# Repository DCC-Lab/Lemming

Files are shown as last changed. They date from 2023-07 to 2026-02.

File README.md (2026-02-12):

# LEM: Lemming Enumeration Module
Authors: Authors: Gabriel Bergeron*, Mireille Quémener*, Thomas Shooner, Christopher Mathault, Nathan Bérubé, Daniel Côté, Dominique Fauteux, Pierre Legagneux

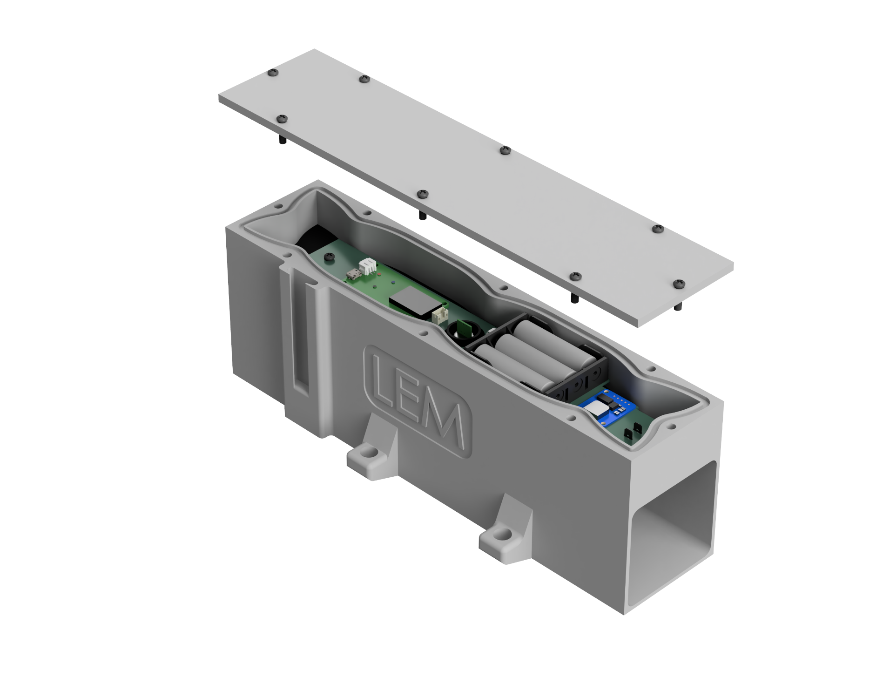
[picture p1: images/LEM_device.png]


## Context
This project focuses on the development of a monitoring device for small mammals, specifically targeting the lemming. The device is designed for deployment in extreme environments, such as the Arctic.

## How it works
The LEM functions as a **passive event logger** using an infrared sensor to detect the passage of small mammals, who emmit IR radiation.
- **Detection Trigger:** The device uses a Passive Infrared (PIR) sensor (AM312) positioned at the intersection of the tunnel and the electronics enclosure. When a small mammal enters the tube, its body heat creates a thermal contrast that triggers the sensor.
- **Wake-on-Interrupt:** To minimize battery consumption, the microcontroller remains in a "deep sleep" state. The PIR sensor is the only component that actively wakes the FireBeetle ESP32 by sending a high signal to a specific I/O pin when motion is detected.
- **Data Logging:** Once awakened, the system immediately pulls a precise date and time from the Real-Time Clock (RTC). This information is saved as a single timestamp entry in the onboard SPIFFS (Serial Peripheral Interface Flash File System) memory. The RTC ensures long-term accurate time keeping even in cold weather. 
- **No Species Identification:** It is important to note that the sensor is **species-blind**; it records the presence of an animal based on heat and motion but cannot distinguish between different small mammals, such as brown lemmings, collared lemmings, or shrews.

### Mechanical Assembly
The LEM device is designed as single-unit instrument to withstand extreme Arctic conditions, including flooding, permafrost, and sub-zero temperatures.
- **Main body:** of a $2.5 \times 2.5$ inch rectangular tunnel integrated with a top-mounted electronics enclosure. The unit is manufactured via thermoplastic molding using black MD-70 polyurethane elastomer, chosen for its durability and resistance to UV degradation and extreme temperatures.
- **Waterproofing:** The electronics lid is secured with screws and sealed against a rubber gasket. The PIR sensor and the power switch are further sealed into the chassis using epoxy resin to prevent water infiltration.
- **Deployment:** The device is placed directly on the ground and secured along small mammal paths using metal pegs. Its tunnel dimensions are specifically designed to be compatible with existing live-traps to ensure consistent animal usage probabilities.

### Electronic System
The LEM circuit is optimized for ultra-low power consumption, enabling autonomous operation in remote environments for over a year on standard AA alkaline batteries.
- **Microcontroller:** we selected the **DFRobot FireBeetle ESP32-E** for its deep-sleep capabilities and 1mW standby power draw (for the circuit in this project).
- **Sensing:** Uses an **AM312 Passive Infrared (PIR) sensor**. When motion is detected in the tunnel, the PIR signal wakes the microcontroller to log the event.
- **Data Logging:** Each detection is recorded as a time-stamped entry in the FireBeetle’s onboard **SPIFFS memory**.
- **Timekeeping:** Includes an **Adafruit PCF8523 Real-Time Clock (RTC)** module powered by a dedicated lithium coin cell to maintain accurate time across deep-sleep cycles and cold-induced power fluctuations.
- **Power Supply:** Operates on **three AA alkaline batteries** (4.5V total). Field tests show the system can maintain sufficient voltage for over 390 days of operation at average temperatures of -9°C.
- **Interface:** Features a waterproof external **rocker switch (ZF Electronics KRE2ANA1BBD)** for field activation/deactivation. Data is retrieved via a standard **USB connection** to the FireBeetle.
- **Custom PCB**: a custom PCB was designed for the spectific needs of this project. 
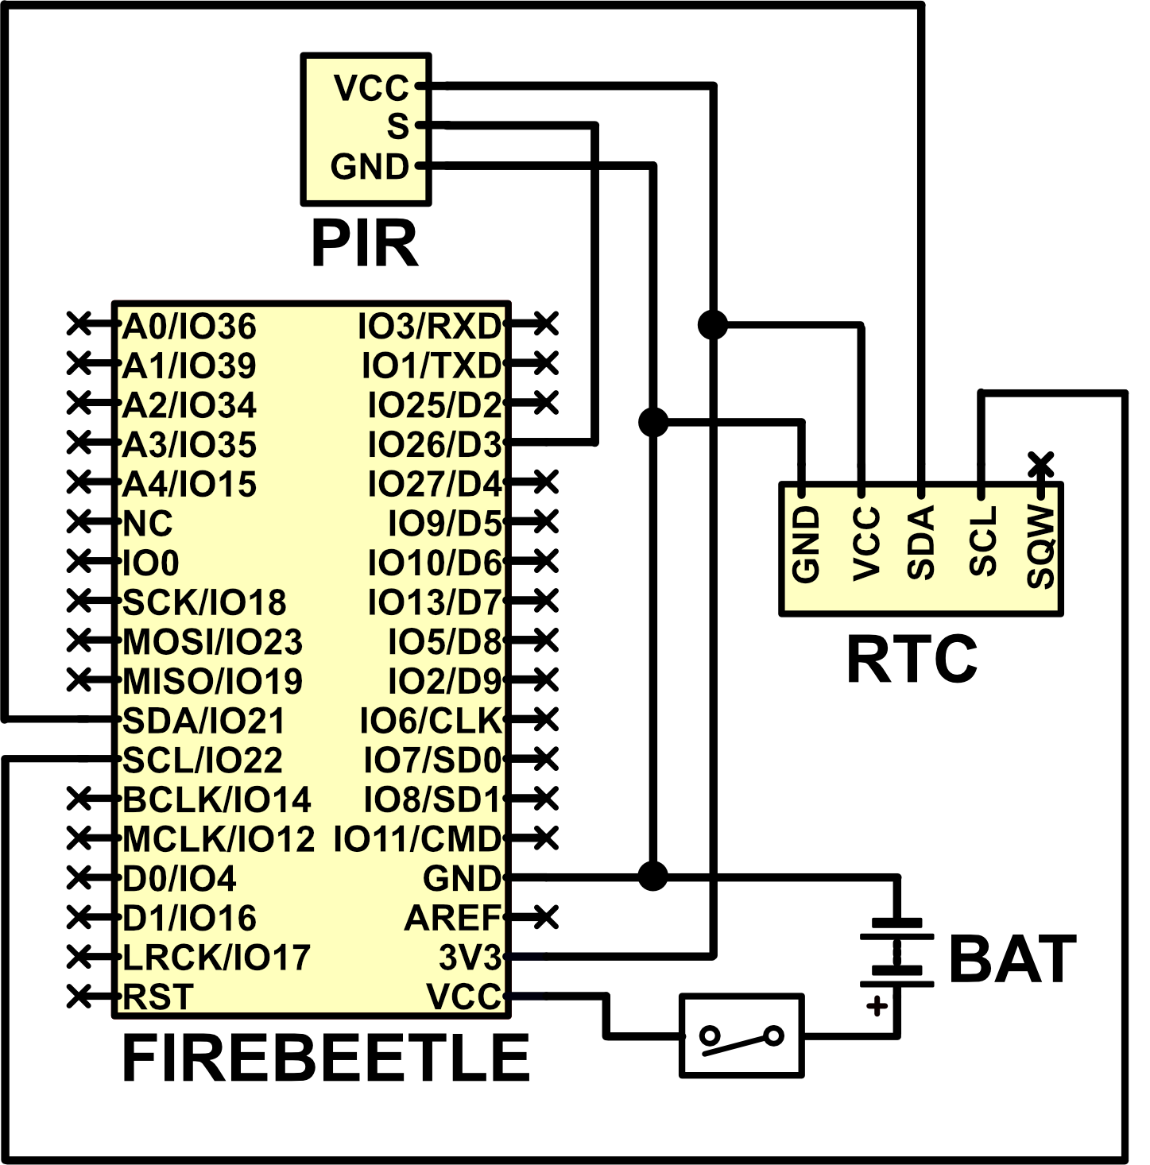
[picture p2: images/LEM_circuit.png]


## What you will find in this repository
**Important:** The LEM device deployed at Bylot Island represents **Version 3**. For the record, two previous prototypes were designed and tested before converging on this final iteration.
### Codes
All Arduino-based source code required for field deployment is located in `Code/v3/SPIFFS_PCF8523`. If you are using the DS1307 RTC module instead of the PCF8523, use the version found in `Code/v3/SPIFFS_DS1307`.

The workflow is divided into three distinct phases to match the deployment cycle:
- **Initialization (`init_lem_v3_pcf8523`):** This code is uploaded to the FireBeetle before field deployment to reinitialize the system and wipe all existing data from the SPIFFS memory. This should be run prior to every new deployment.
- **Deployment (`main_lem_v3_pcf8523`):** Once initialized, upload this code to place the device into "deployment mode". When the rocker switch is toggled on, the device creates a "startFile" with a timestamp to mark the beginning of the session and begins logging lemming activity. Every power cycle (off/on) generates a new timestamped "startFile".
- **Data Retrieval (`read_lem_v3_pcf8523`):** After retrieving the device from the field and powering it down, upload this code to output the stored SPIFFS data to the serial terminal.

**Data Downloader Utility:** After uploading the retrieval code, you can use our standalone desktop utility (available for Windows 64-bit) to download data directly to your computer. This utility includes a simple UI to select the FireBeetle's COM port and your destination folder. You can find this program under the **Releases** section.

### CAD files
The `CAD` folder contains **STEP files** of the full LEM assembly. Native project files (Fusion360 or SolidWorks) are available upon request.

### PCB files
**Gerber files** for the PCB are located in `PCB/LEM_v3/gerberFiles`.

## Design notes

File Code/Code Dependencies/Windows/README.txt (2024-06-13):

firebeetle32 should be placed in your packages folder.
It will give you access to the board manager FireBeetle - ESP32 Mainboard.

The packages folder can be found somewhere like this : C:\Users\ludov\AppData\Local\Arduino15\packages

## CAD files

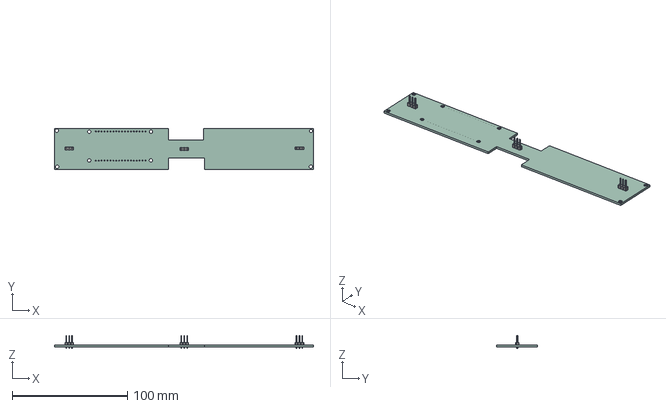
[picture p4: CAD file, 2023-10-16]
Circuit/v2/PCB_firebeetle/Lemmingometre/Lemmingometre.step
225.0 x 35.6 x 11.5 mm
_autosave-Lemmingometre PCB

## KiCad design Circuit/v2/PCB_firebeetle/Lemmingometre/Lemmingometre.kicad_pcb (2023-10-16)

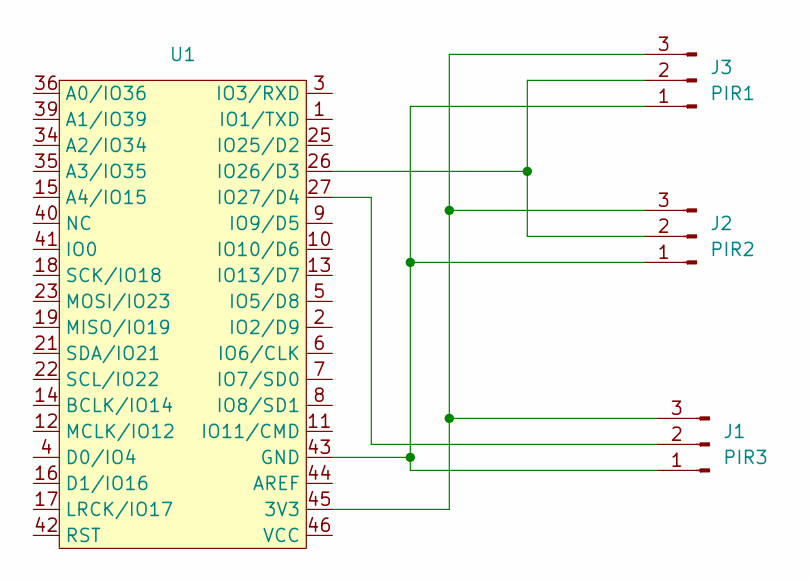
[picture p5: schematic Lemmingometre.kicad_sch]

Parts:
J1: PIR3; PinHeader_1x03_P2.54mm_Vertical
J2: PIR2; PinHeader_1x03_P2.54mm_Vertical
J3: PIR1; PinHeader_1x03_P2.54mm_Vertical
U1: Firebeetle

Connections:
unnamed: J1.1, J2.1, J3.1, U1.43 (GND)
unnamed: J1.2, U1.27 (IO27/D4)
unnamed: J1.3, J2.3, J3.3, U1.45 (3V3)
unnamed: J2.2, J3.2, U1.26 (IO26/D3)

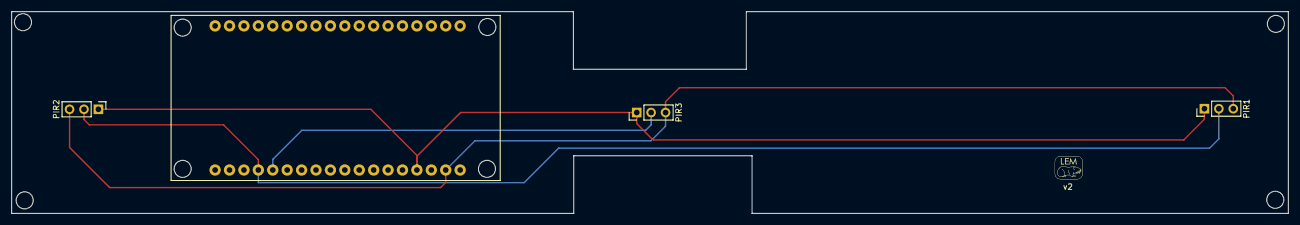
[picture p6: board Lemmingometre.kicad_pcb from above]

Board: 2 copper layers, 225.0 x 35.6 mm, 4 parts (1 on the bottom side), 4 nets.

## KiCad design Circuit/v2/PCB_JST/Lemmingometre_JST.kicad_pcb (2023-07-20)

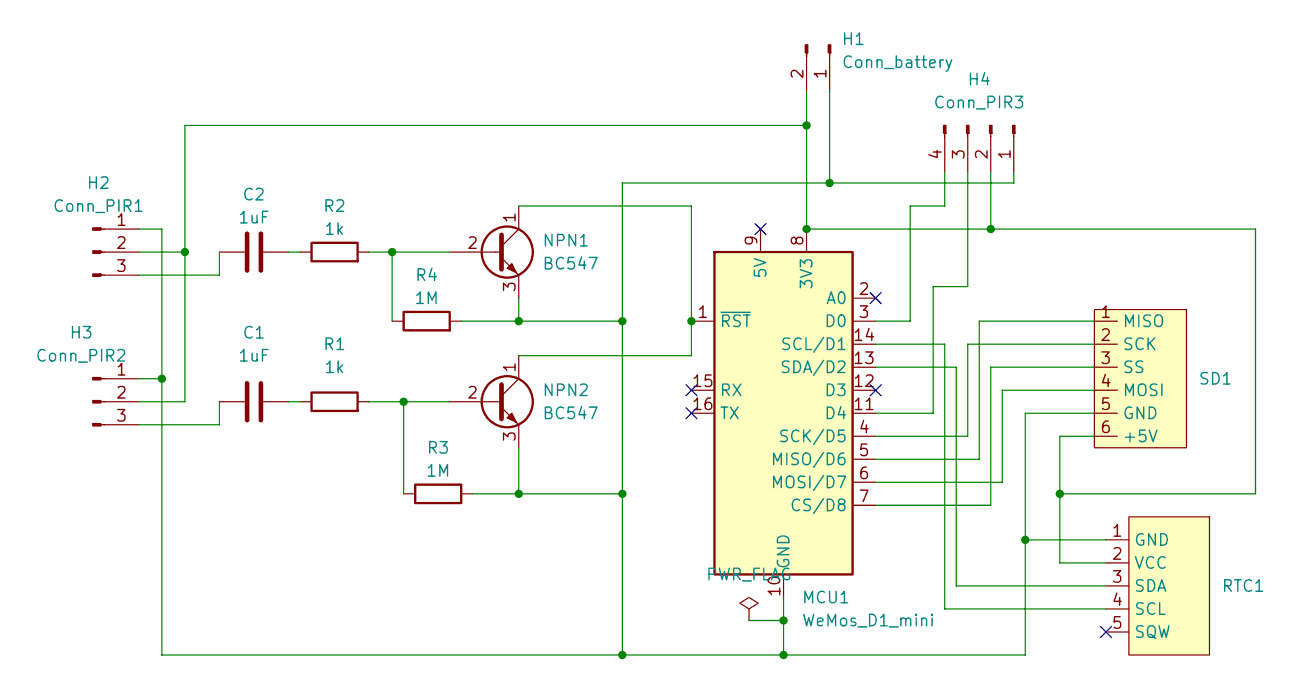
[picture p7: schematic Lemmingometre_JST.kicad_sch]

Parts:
C1, C2: 1uF; C_Disc_D5.0mm_W2.5mm_P2.50mm
H1: Conn_battery; JST_PH_B2B-PH-K_1x02_P2.00mm_Vertical
H2: Conn_PIR1; JST_PH_B3B-PH-K_1x03_P2.00mm_Vertical
H3: Conn_PIR2; JST_PH_B3B-PH-K_1x03_P2.00mm_Vertical
H4: Conn_PIR3; JST_PH_B4B-PH-K_1x04_P2.00mm_Vertical
MCU1: WeMos_D1_mini; WEMOS_D1_mini_light
NPN1, NPN2: BC547; TO-92_Inline
R1, R2: 1k; R_Axial_DIN0207_L6.3mm_D2.5mm_P7.62mm_Horizontal
R3, R4: 1M; R_Axial_DIN0207_L6.3mm_D2.5mm_P7.62mm_Horizontal
RTC1: Adafruit PCF8523
SD1: DFRobot micro SD module

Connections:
unnamed: C1.2, R1.1
unnamed: C2.2, R2.1
unnamed: H1.1, H2.1, H3.1, H4.1, MCU1.10 (GND), NPN1.3 (E), NPN2.3 (E), R3.2, R4.2, RTC1.1 (GND), SD1.5 (GND)
unnamed: H1.2, H2.2, H3.2, H4.2, MCU1.8 (3V3), RTC1.2 (VCC), SD1.6 (+5V)
unnamed: C2.1, H2.3
unnamed: C1.1, H3.3
unnamed: H4.3, MCU1.11 (D4)
unnamed: H4.4, MCU1.3 (D0)
unnamed: MCU1.7 (CS/D8), SD1.3 (SS)
unnamed: MCU1.5 (MISO/D6), SD1.1 (MISO)
unnamed: MCU1.6 (MOSI/D7), SD1.4 (MOSI)
unnamed: MCU1.4 (SCK/D5), SD1.2 (SCK)
unnamed: MCU1.14 (SCL/D1), RTC1.4 (SCL)
unnamed: MCU1.13 (SDA/D2), RTC1.3 (SDA)
unnamed: MCU1.1 (~RST), NPN1.1 (C), NPN2.1 (C)
unnamed: NPN1.2 (B), R2.2, R4.1
unnamed: NPN2.2 (B), R1.2, R3.1

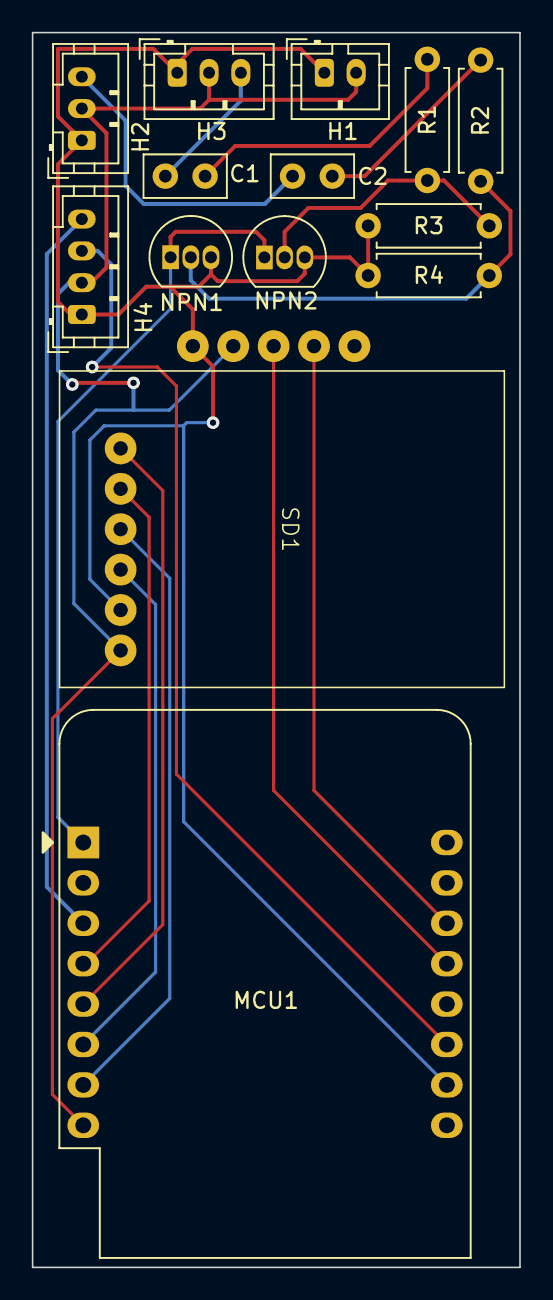
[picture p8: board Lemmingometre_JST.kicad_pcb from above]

Board: 2 copper layers, 30.6 x 77.6 mm, 15 parts (1 on the bottom side), 17 nets.

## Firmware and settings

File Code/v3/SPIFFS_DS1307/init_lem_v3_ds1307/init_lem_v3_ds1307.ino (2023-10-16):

#include "FS.h"
#include "SPIFFS.h"
#include <DFRobot_DS1307.h>
#include <ESP32Time.h>
#include <vector>

#define FORMAT_SPIFFS_IF_FAILED true

DFRobot_DS1307 DS1307;
ESP32Time rtc;

uint16_t getTimeBuff[7];

void setup(){
  Serial.begin(115200);

  if(!SPIFFS.begin(FORMAT_SPIFFS_IF_FAILED)){
      Serial.println("SPIFFS Mount Failed");
      return;
  }
  pinMode(GPIO_NUM_26, OUTPUT);
  digitalWrite(GPIO_NUM_26, HIGH);
  DS1307.begin();
  
  uint16_t setTimeBuff[7] = {0, 22, 13, 1, 12, 10, 2023};
  DS1307.setTime(setTimeBuff);
  DS1307.start();
  DS1307.setSqwPinMode(DS1307.eSquareWave_1Hz);






// ##### CE CODE PERMET DE VOIR LE NOM DES FICHIERS CRÉER DANS LE SPIFFS ####


  // listAndSendFiles("/");

  // listDir(SPIFFS, "/", 0); // Voir la liste des fichiers contenu dans le SPIFFS

  // readFile(SPIFFS, "/0003-349235"); // Ouvrir et lire un fichier contenu dans le SPIFFS avec le nom "/exemple.txt"

  // appendFile(SPIFFS, "/hello.txt", "World!\r\n"); // Ajouter du contenu au fichier "exemple.txt"

  // renameFile(SPIFFS, "/exemple.txt", "/exemple2.txt");  // Renommer le fichier "/exemple.txt" vers "exemple2.txt"
   
  // deleteFile(SPIFFS, "/exemple2.txt"); // Supprimer le fichier "exemple2.txt"

  // createFile(SPIFFS, "/hello.txt");  // Créer le fichier "hello.txt"
  // listDir(SPIFFS, "/", 0);


  // #### ATTENTION, CETTE FONCTION SUPPRIME L'ENTIÈRETÉ DES FICHERS CONTENUS DANS LE SPIFFS #####

  deleteAllFiles(SPIFFS, "/"); // Supprimer tous les fichier du SPIFFS
  listDir(SPIFFS, "/", 0);

  delay(5000);
  DS1307.getTime(getTimeBuff);
  for(int i = 0; i < 7; i++){
  Serial.print(getTimeBuff[i]);
  }
}

void loop() {
  // if (Serial.available() > 0) {
  //   char incomingChar = Serial.read(); // Read the incoming character

  //   if (incomingChar == 'R') {
  //     // Send data to Python when 'R' is received
  //     listAndSendFiles("/");
  //   }
  // }
}


/*

// void listDir(fs::FS &fs, const char * dirname, uint8_t levels){
//     Serial.printf("Listing directory: %s\r\n", dirname);

//     File root = fs.open(dirname);
//     if(!root){
//         Serial.println("- failed to open directory");
//         return;
//     }
//     if(!root.isDirectory()){
//         Serial.println(" - not a directory");
//         return;
//     }

//     File file = root.openNextFile();
//     while(file){
//         if(file.isDirectory()){
//             Serial.print("  DIR : ");
//             Serial.println(file.name());
//             if(levels){
//                 listDir(fs, file.name(), levels -1);
//             }
//         } else {
//             Serial.print("  FILE: ");
//             Serial.print(file.name());
//             Serial.print("\tSIZE: ");
//             Serial.println(file.size());
//         }
//         file = root.openNextFile();
//     }
// }

*/

void listDir(fs::FS &fs, const char *dirname, uint8_t levels) {
    Serial.printf("Listing directory: %s\r\n", dirname);

    File root = fs.open(dirname);
    if (!root) {
        Serial.println("- failed to open directory");
        return;
    }
    if (!root.isDirectory()) {
        Serial.println(" - not a directory");
        return;
    }

    std::vector<String> fileNames;

    File file = root.openNextFile();
    while (file) {
        if (file.isDirectory()) {
            fileNames.push_back(String(file.name()) + "/");
        } else {
            fileNames.push_back(file.name());
        }

        file = root.openNextFile();
    }

    std::sort(fileNames.begin(), fileNames.end());

    for (const String &name : fileNames) {
        Serial.print("  ");
        if (levels > 0 && name.endsWith("/")) {
            Serial.print("DIR : ");
            Serial.println(name);
            listDir(fs, (dirname + name).c_str(), levels - 1);
        } else {
            Serial.print("FILE: ");
            Serial.print(name);
            File file = fs.open((dirname + name).c_str());
            Serial.print("\tSIZE: ");
            Serial.println(file.size());
            file.close();
        }
    }
}

void listAndSendFiles(const char *dirname) {
    File root = SPIFFS.open(dirname);
    if (!root) {
        Serial.println("- failed to open directory");
        return;
    }
    if (!root.isDirectory()) {
        Serial.println(" - not a directory");
        return;
    }

    File file = root.openNextFile();
    while (file) {
        if (file.isDirectory()) {
            // Recursively list and send files in subdirectories
            listAndSendFiles(file.name());
        } else {
            // Read and send the content of the file
            Serial.print("Sending file: ");
            Serial.println(file.name());
            while (file.available()) {
                Serial.write(file.read());
            }
            Serial.println("End of file"); // Add a newline to indicate the end of the file
        }
        file = root.openNextFile();
    }
  Serial.println("End");
}

void readFile(fs::FS &fs, const char * path){
    Serial.printf("Reading file: %s\r\n", path);

    File file = fs.open(path);
    if(!file || file.isDirectory()){
        Serial.println("- failed to open file for reading");
        return;
    }

    Serial.println("- read from file:");
    while(file.available()){
        Serial.write(file.read());
    }
}

void writeFile(fs::FS &fs, const char * path, const char * message){
    Serial.printf("Writing file: %s\r\n", path);

    File file = fs.open(path, FILE_WRITE);
    if(!file){
        Serial.println("- failed to open file for writing");
        return;
    }
    if(file.print(message)){
        Serial.println("- file written");
    } else {
        Serial.println("- frite failed");
    }
}

void createFile(fs::FS &fs, const char * path){
  Serial.printf("Creating file: %s\r\n", path);
  File file = fs.open(path, FILE_WRITE);
}

void appendFile(fs::FS &fs, const char * path, const char * message){
    Serial.printf("Appending to file: %s\r\n", path);

    File file = fs.open(path, FILE_APPEND);
    if(!file){
        Serial.println("- failed to open file for appending");
        return;
    }
    if(file.print(message)){
        Serial.println("- message appended");
    } else {
        Serial.println("- append failed");
    }
}

void renameFile(fs::FS &fs, const char * path1, const char * path2){
    Serial.printf("Renaming file %s to %s\r\n", path1, path2);
    if (fs.rename(path1, path2)) {
        Serial.println("- file renamed");
    } else {
        Serial.println("- rename failed");
    }
}

void deleteFile(fs::FS &fs, const char * path){
    Serial.printf("Deleting file: %s\r\n", path);
    if(fs.remove(path)){
        Serial.println("- file deleted");
    } else {
        Serial.println("- delete failed");
    }
}

void deleteAllFiles(fs::FS &fs, const String &dirPath) {
    Serial.printf("Deleting files in directory: %s\r\n", dirPath.c_str());

    File dir = fs.open(dirPath.c_str());
    if (!dir || !dir.isDirectory()) {
        Serial.println("- not a valid directory");
        return;
    }

    File file = dir.openNextFile();
    while (file) {
        String filePath = file.name();
        if (fs.remove(filePath.c_str())) {
            Serial.println("- deleted file: " + filePath);
        } else {
            Serial.println("- delete failed for file: " + filePath);
        }
        file = dir.openNextFile();
    }
}

int countFilesInDirectory(fs::FS &fs, const String &dirPath) {
    int fileCount = 0;

    File dir = fs.open(dirPath.c_str());
    if (!dir || !dir.isDirectory()) {
        return -1; // Directory doesn't exist or isn't valid
    }

    File file = dir.openNextFile();
    while (file) {
        if (!file.isDirectory()) {
            fileCount++;
        }
        file = dir.openNextFile();
    }

    return fileCount;
}

int countFilesWithBaseName(fs::FS &fs, const String &dirPath, const String &baseName) {
    int fileCount = 0;

    File dir = fs.open(dirPath.c_str());
    if (!dir || !dir.isDirectory()) {
        return fileCount; // Directory doesn't exist or isn't valid
    }

    File file = dir.openNextFile();
    while (file) {
        if (!file.isDirectory() && String(file.name()).startsWith("/" + baseName)) {
            fileCount++;
        }
        file = dir.openNextFile();
    }

    return fileCount;
}

String get_create_FileName() {
  char epochStr[20];
  char fileName[30]; // Adjusted length for number of files and separators
  itoa(rtc.getEpoch(), epochStr, 10);
  
  String directoryPath = "/"; // Replace with your directory path
  int numOfFiles = countFilesInDirectory(SPIFFS, directoryPath);
  
  sprintf(fileName, "/%04d-%s", numOfFiles, epochStr);
  
  createFile(SPIFFS, fileName);
  
  Serial.print("New file created at: ");
  Serial.println(rtc.getEpoch());
  
  return String(fileName);
}

String get_create_startFile(){
  char fileName[30]; // Adjusted length for number of files and separators
  
  String directoryPath = "/"; // Replace with your directory path
  int numOfFiles = countFilesInDirectory(SPIFFS, directoryPath);
  
  sprintf(fileName, "/%04d-%s", numOfFiles, "startFile");
  
  createFile(SPIFFS, fileName);
  
  return String(fileName);
}

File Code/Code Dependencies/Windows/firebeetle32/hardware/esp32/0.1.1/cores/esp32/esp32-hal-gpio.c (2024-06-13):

// Copyright 2015-2016 Espressif Systems (Shanghai) PTE LTD
//
// Licensed under the Apache License, Version 2.0 (the "License");
// you may not use this file except in compliance with the License.
// You may obtain a copy of the License at

//     http://www.apache.org/licenses/LICENSE-2.0
//
// Unless required by applicable law or agreed to in writing, software
// distributed under the License is distributed on an "AS IS" BASIS,
// WITHOUT WARRANTIES OR CONDITIONS OF ANY KIND, either express or implied.
// See the License for the specific language governing permissions and
// limitations under the License.

#include "esp32-hal-gpio.h"
#include "freertos/FreeRTOS.h"
#include "freertos/task.h"
#include "rom/ets_sys.h"
#include "esp_attr.h"
#include "esp_intr.h"
#include "rom/gpio.h"
#include "soc/gpio_reg.h"
#include "soc/io_mux_reg.h"
#include "soc/gpio_struct.h"
#include "soc/rtc_io_reg.h"

const int8_t esp32_adc2gpio[20] = {36, 37, 38, 39, 32, 33, 34, 35, -1, -1, 4, 0, 2, 15, 13, 12, 14, 27, 25, 26};

const DRAM_ATTR esp32_gpioMux_t esp32_gpioMux[GPIO_PIN_COUNT]={
    {0x44, 11, 11, 1},
    {0x88, -1, -1, -1},
    {0x40, 12, 12, 2},
    {0x84, -1, -1, -1},
    {0x48, 10, 10, 0},
    {0x6c, -1, -1, -1},
    {0x60, -1, -1, -1},
    {0x64, -1, -1, -1},
    {0x68, -1, -1, -1},
    {0x54, -1, -1, -1},
    {0x58, -1, -1, -1},
    {0x5c, -1, -1, -1},
    {0x34, 15, 15, 5},
    {0x38, 14, 14, 4},
    {0x30, 16, 16, 6},
    {0x3c, 13, 13, 3},
    {0x4c, -1, -1, -1},
    {0x50, -1, -1, -1},
    {0x70, -1, -1, -1},
    {0x74, -1, -1, -1},
    {0x78, -1, -1, -1},
    {0x7c, -1, -1, -1},
    {0x80, -1, -1, -1},
    {0x8c, -1, -1, -1},
    {0, -1, -1, -1},
    {0x24, 6, 18, -1}, //DAC1
    {0x28, 7, 19, -1}, //DAC2
    {0x2c, 17, 17, 7},
    {0, -1, -1, -1},
    {0, -1, -1, -1},
    {0, -1, -1, -1},
    {0, -1, -1, -1},
    {0x1c, 9, 4, 9},
    {0x20, 8, 5, 8},
    {0x14, 4, 6, -1},
    {0x18, 5, 7, -1},
    {0x04, 0, 0, -1},
    {0x08, 1, 1, -1},
    {0x0c, 2, 2, -1},
    {0x10, 3, 3, -1}
};

typedef void (*voidFuncPtr)(void);
typedef void (*voidFuncPtrArg)(void*);
typedef struct {
    voidFuncPtr fn;
    void* arg;
    bool functional;
} InterruptHandle_t;
static InterruptHandle_t __pinInterruptHandlers[GPIO_PIN_COUNT] = {0,};

#include "driver/rtc_io.h"

extern void IRAM_ATTR __pinMode(uint8_t pin, uint8_t mode)
{

    if(!digitalPinIsValid(pin)) {
        return;
    }

    uint32_t rtc_reg = rtc_gpio_desc[pin].reg;
    if(mode == ANALOG) {
        if(!rtc_reg) {
            return;//not rtc pin
        }
        //lock rtc
        uint32_t reg_val = ESP_REG(rtc_reg);
        if(reg_val & rtc_gpio_desc[pin].mux){
            return;//already in adc mode
        }
        reg_val &= ~(
                (RTC_IO_TOUCH_PAD1_FUN_SEL_V << rtc_gpio_desc[pin].func)
                |rtc_gpio_desc[pin].ie
                |rtc_gpio_desc[pin].pullup
                |rtc_gpio_desc[pin].pulldown);
        ESP_REG(RTC_GPIO_ENABLE_W1TC_REG) = (1 << (rtc_gpio_desc[pin].rtc_num + RTC_GPIO_ENABLE_W1TC_S));
        ESP_REG(rtc_reg) = reg_val | rtc_gpio_desc[pin].mux;
        //unlock rtc
        ESP_REG(DR_REG_IO_MUX_BASE + esp32_gpioMux[pin].reg) = ((uint32_t)2 << MCU_SEL_S) | ((uint32_t)2 << FUN_DRV_S) | FUN_IE;
        return;
    }

    //RTC pins PULL settings
    if(rtc_reg) {
        //lock rtc
        ESP_REG(rtc_reg) = ESP_REG(rtc_reg) & ~(rtc_gpio_desc[pin].mux);
        if(mode & PULLUP) {
            ESP_REG(rtc_reg) = (ESP_REG(rtc_reg) | rtc_gpio_desc[pin].pullup) & ~(rtc_gpio_desc[pin].pulldown);
        } else if(mode & PULLDOWN) {
            ESP_REG(rtc_reg) = (ESP_REG(rtc_reg) | rtc_gpio_desc[pin].pulldown) & ~(rtc_gpio_desc[pin].pullup);
        } else {
            ESP_REG(rtc_reg) = ESP_REG(rtc_reg) & ~(rtc_gpio_desc[pin].pullup | rtc_gpio_desc[pin].pulldown);
        }
        //unlock rtc
    }

    uint32_t pinFunction = 0, pinControl = 0;

    //lock gpio
    if(mode & INPUT) {
        if(pin < 32) {
            GPIO.enable_w1tc = ((uint32_t)1 << pin);
        } else {
            GPIO.enable1_w1tc.val = ((uint32_t)1 << (pin - 32));
        }
    } else if(mode & OUTPUT) {
        if(pin > 33){
            //unlock gpio
            return;//pins above 33 can be only inputs
        } else if(pin < 32) {
            if(pin == 10 || pin == 9){
                gpio_set_direction(pin, GPIO_MODE_OUTPUT);
            }
            GPIO.enable_w1ts = ((uint32_t)1 << pin);
        } else {
            GPIO.enable1_w1ts.val = ((uint32_t)1 << (pin - 32));
        }
    }

    if(mode & PULLUP) {
        pinFunction |= FUN_PU;
    } else if(mode & PULLDOWN) {
        pinFunction |= FUN_PD;
    }

    pinFunction |= ((uint32_t)2 << FUN_DRV_S);//what are the drivers?
    pinFunction |= FUN_IE;//input enable but required for output as well?
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

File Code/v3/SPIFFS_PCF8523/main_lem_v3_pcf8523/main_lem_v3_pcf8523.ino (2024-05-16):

/*
    *** Main LEM Device ***

    This is the main code that will allow the LEM device to count the lemmings. 
    When you upload the code on the LEM device for the first time, it will create a "setupFile" on its memory and ask you to unplug the device. 
    Then, the LEM device is ready to be deployed on the field. 
    Each time the LEM device is powered off and then powered on again, it will create a startFile. 
    If the PIR sensor detects a lemming, it will create a new .txt file named with the timestamp of the detection. 

    This code should be used AFTER running the "Initialize LEM Device" code.
    
    The circuit:
    This code should be used with the LEM v3 circuit board with this hardware:
    - FIREBEETLE ESP32 (DFR0478)
    - PCF8523 RTC
    - PIR sensor

    Authors:
    Mireille Quémener
    Thomas Shooner
*/

#include "FS.h"
#include "SPIFFS.h"
#include <ESP32Time.h>
#include "RTClib.h"

#define BUTTON_PIN_BITMASK 0x200000000  // 2^33 in hex
#define FORMAT_SPIFFS_IF_FAILED true

char fileName[50];

RTC_PCF8523 rtc;

RTC_DATA_ATTR bool firstCount = true;
RTC_DATA_ATTR int obstacleAcquisitionTime = 20000;  // trigger pendant 10 sec

int obstacleValue;

void setup() {
  Serial.begin(115200);
  SPIFFS.begin(false);

  pinMode(GPIO_NUM_26, INPUT);  //ObstacleSensor

  Serial.println("-------------------------");
  setupRTC();
  Serial.println("-------------------------");

  // If LEM device is powered on for the first time
  if (firstCount) { 

    // If there is already a setupFile on the SPIFFS, create a startFile
    if (doesFileExistInDirectory(SPIFFS, "/", "/setupFile")) {
      get_create_startFile();
      firstCount = false;
    }

    // If there is no setupFile on the SPIFFS, create one.
    else {
      delay(5000);
      Serial.println(" ");
      Serial.println("*** Main LEM Device ***");
      Serial.println("This code is uploaded on the LEM device for the first time. Let's create a setupFile.");
      writeFile(SPIFFS, "/setupFile", "Lemming Enumeration Module started!");
      listDir(SPIFFS, "/", 0);

      if (doesFileExistInDirectory(SPIFFS, "/", "/setupFile")) {
        Serial.println("The setupFile has been created successfully!");
        Serial.println("Disconnect LEM device now. Do not upload the code again or reboot the LEM device.");
      } else {
        Serial.println("setupFile creation has failed.");
      }
      delay(60000);
    }
  }

  // If the LEM device has aleady been powered on before (or if there is already a setupFile AND a startFile)
  else {
    String fileName = get_create_FileName();
    unsigned long startTime = millis();
    while (millis() - startTime < obstacleAcquisitionTime) {
      obstacleValue = readObstacleSensor();
      Serial.println(obstacleValue);
      appendFile(SPIFFS, fileName, String(obstacleValue));
      appendFile(SPIFFS, fileName, "\r\n");
      delay(200);
    }
  }

  // Deep sleep until the PIR detects a new lemming
  esp_sleep_enable_ext0_wakeup(GPIO_NUM_26, RISING);
  esp_deep_sleep_start();
}

void loop() {
}

void setupRTC() {
  if (!rtc.begin()) {
    Serial.println("Couldn't find RTC.");
    Serial.println("Please verify there is a battery in the RTC chip.");
    Serial.flush();
    while (1) delay(10);
  } else {
    Serial.println("RTC setup succeded.");
  }
  rtc.start();
}

void listDir(fs::FS &fs, const String &dirname, uint8_t levels) {
  Serial.printf("Listing directory: %s\r\n", dirname.c_str());

  File root = fs.open(dirname.c_str());
  if (!root) {
    Serial.println("- failed to open directory");
    return;
  }
  if (!root.isDirectory()) {
    Serial.println(" - not a directory");
    return;
  }

  File file = root.openNextFile();
  while (file) {
    if (file.isDirectory()) {
      Serial.print("  DIR : ");
      Serial.println(file.name());
      if (levels) {
        listDir(fs, file.name(), levels - 1);
      }
    } else {
      Serial.print("  FILE: ");
      Serial.print(file.name());
      Serial.print("\tSIZE: ");
      Serial.println(file.size());
    }
    file = root.openNextFile();
  }
}

void writeFile(fs::FS &fs, const String &path, const String &message) {
  // Serial.printf("Writing file: %s\r\n", path.c_str());

  File file = fs.open(path.c_str(), FILE_WRITE);
  if (!file) {
    // Serial.println("- failed to open file for writing");
    return;
  }
  if (file.print(message)) {
    // Serial.println("- file written");
  } else {
    // Serial.println("- write failed");
  }
}

void createFile(fs::FS &fs, const String &path) {
  // Serial.printf("Creating file: %s\r\n", path.c_str());
  File file = fs.open(path.c_str(), FILE_WRITE);
}

void appendFile(fs::FS &fs, const String &path, const String &message) {
  // Serial.printf("Appending to file: %s\r\n", path.c_str());

  File file = fs.open(path.c_str(), FILE_APPEND);
  if (!file) {
    // Serial.println("- failed to open file for appending");
    return;
  }
  if (file.print(message)) {
    // Serial.println("- message appended");
  } else {
    // Serial.println("- append failed");
  }
}

bool doesFileExistInDirectory(fs::FS &fs, const String &dirPath, const String &fileName) {
  File dir = fs.open(dirPath.c_str());
  if (!dir || !dir.isDirectory()) {
    return false;  // Directory doesn't exist or isn't valid
  }

  File file = dir.openNextFile();
  while (file) {
    if (file.isDirectory()) {
      file = dir.openNextFile();
      continue;
    }

    if (fileName.equals(file.name())) {
      return true;  // File with the same name exists in the directory
    }

    file = dir.openNextFile();
  }

  return false;  // File with the specified name doesn't exist in the directory
}

int countFilesInDirectory(fs::FS &fs, const String &dirPath) {
  int fileCount = 0;

  File dir = fs.open(dirPath.c_str());
  if (!dir || !dir.isDirectory()) {
    return -1;  // Directory doesn't exist or isn't valid
  }

  File file = dir.openNextFile();
  while (file) {
    if (!file.isDirectory()) {
      fileCount++;
    }
    file = dir.openNextFile();
  }

  return fileCount;
}

int readObstacleSensor() {
  return digitalRead(GPIO_NUM_26);
}

String get_create_FileName() {
  String directoryPath = "/";  // Replace with your directory path
  int numOfFiles = countFilesInDirectory(SPIFFS, directoryPath);
  DateTime now = rtc.now();
  snprintf(fileName, 50, "/%04d-%d%d%d%d%d%d", numOfFiles, now.year(), now.month(), now.day(), now.hour(), now.minute(), now.second());
  createFile(SPIFFS, fileName);

  return String(fileName);
}

String get_create_startFile() {
  char fileName[30];  // Adjusted length for number of files and separators

  String directoryPath = "/";  // Replace with your directory path
  int numOfFiles = countFilesInDirectory(SPIFFS, directoryPath);

  sprintf(fileName, "/%04d-%s", numOfFiles, "startFile");

  createFile(SPIFFS, fileName);

  return String(fileName);
}

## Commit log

2023-07-07 Upload kicad files
    [Lemmingometre.kicad_pcb, Lemmingometre.kicad_sch]
2023-07-07 Added PCB and Arduino files
    [Lemmingometre_v2-B_Cu.gbr, Lemmingometre_v2-B_Mask.gbr, Lemmingometre_v2-B_Paste.gbr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]
2023-07-12 changed schematic and pcb
    [Lemmingometre.kicad_pcb, Lemmingometre.kicad_sch]
2023-07-12 Changed from IR to PIR sensor
    [Lemmingometre.kicad_pcb]
2023-07-13 spaced pcb routes
    [Lemmingometre.kicad_pcb, Lemmingometre.kicad_sch]
2023-07-20 Add kicad file JST pins
    [Lemmingometre_JST.kicad_pcb, Lemmingometre_JST.kicad_sch]
2023-07-20 Add Gerber files
    [Lemmingometre_JST-B_Cu.gbr, Lemmingometre_JST-B_Mask.gbr, Lemmingometre_JST-B_Paste.gbr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]
2023-07-20 Adaptation to PIR sensor as obstacle sensor
    Change pin number and remove inversion of reading of the sensor.
2024-03-14 removed pin 27
2024-06-04 added firebeetle32 dependency with windows compiled files
    [app3M_fat9M_16MB.csv, default.csv, default_16MB.csv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]
2024-06-05 rtc battery check in init_lem
2024-06-05 added ui and button, there is a dependency bug
    [SerialReader.py]
2024-06-06 added port refresh for when you plug in a new device only after starting the program
2024-06-06 Added error handling with message for when you forget to stop the serial monitor
    [SerialReader.py]
2024-06-06 fixed uncaught exception on PermissionError
    [SerialReader.py]
2024-06-13 remove unused ESP32Time library
2026-02-12 added gerber files
    [LEM_v3-B_Cu.gbr, LEM_v3-B_Mask.gbr, LEM_v3-B_Paste.gbr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]
